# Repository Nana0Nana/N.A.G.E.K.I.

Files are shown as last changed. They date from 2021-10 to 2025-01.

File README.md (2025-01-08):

# N.A.G.E.K.I.
# [PLEASE CHECK Main Project](https://github.com/Nana0Nana/NAGEKI)
# ↑ This page dont have update,please check the main ↑
# 这个页面停止更新，请查看主项目↑↑

## A cheap，simple，Ongeki controller Use Keyboard Simulation and Mouse Simulation to controller the ongeki game. Using Pro-micro control.
## [中文版介绍 Chinese version](https://github.com/Nana0Nana/N.A.G.E.K.I./blob/main/README_CN.md)

# Befor download

## FOR All the blueprint,I __didnt__ do the Screw holes, so thats mean you need use drill to creat a hold for screw,I use M3x25 screw to fix all the part.

# First
## you need print the PCB and you need a Promicro to control.

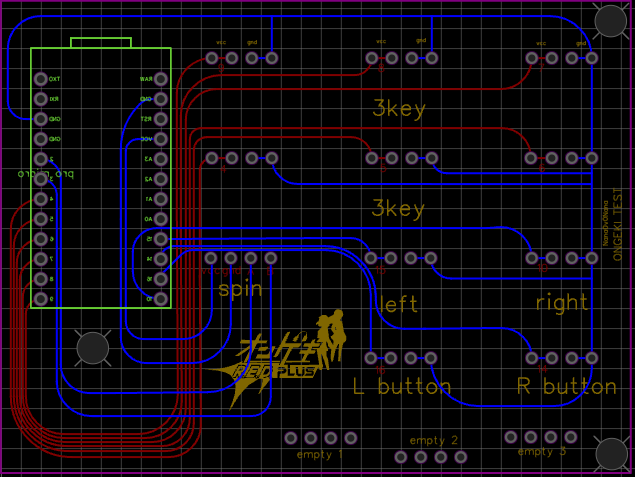
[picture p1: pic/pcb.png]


## I already ping the ports out so you just need connect them.

# For main.

I recommend you use the 15 or 20mm Density wood board

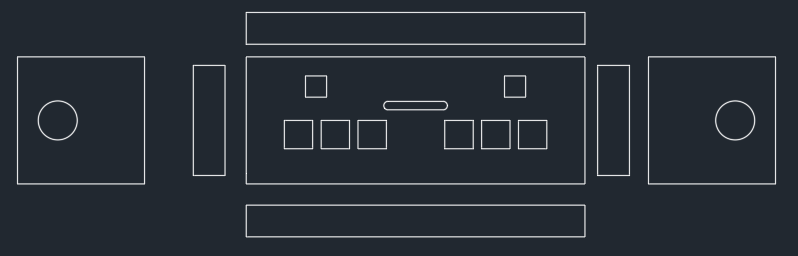
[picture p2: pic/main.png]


## details

For the main button,I get 67x67mm hole,thats a really big size than the button you got.But you will get the Acrylic board,that will fix the hole.
you need 60x60mm button.

for menu button,I get 50x50mm hole,same,that hold will a bit large than the button size,so you need the Acrylic board.
you nedd 44x44mm button

for side button,I use the 100x100mm button,thats the cheap and easy way to solve the side button problem.
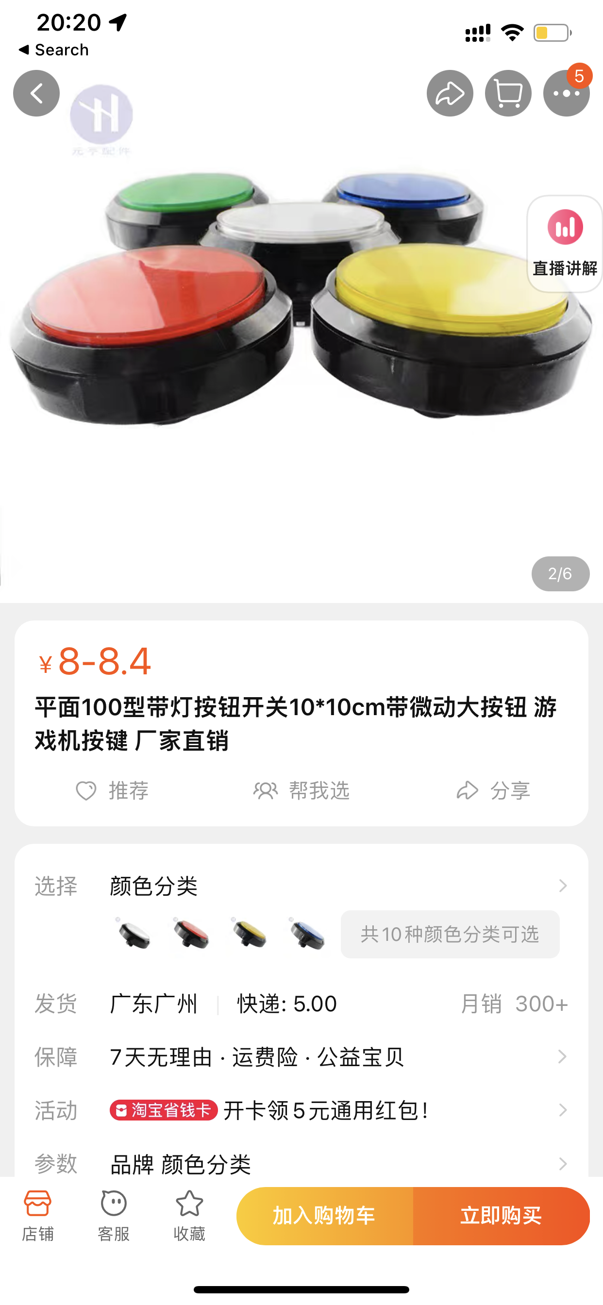
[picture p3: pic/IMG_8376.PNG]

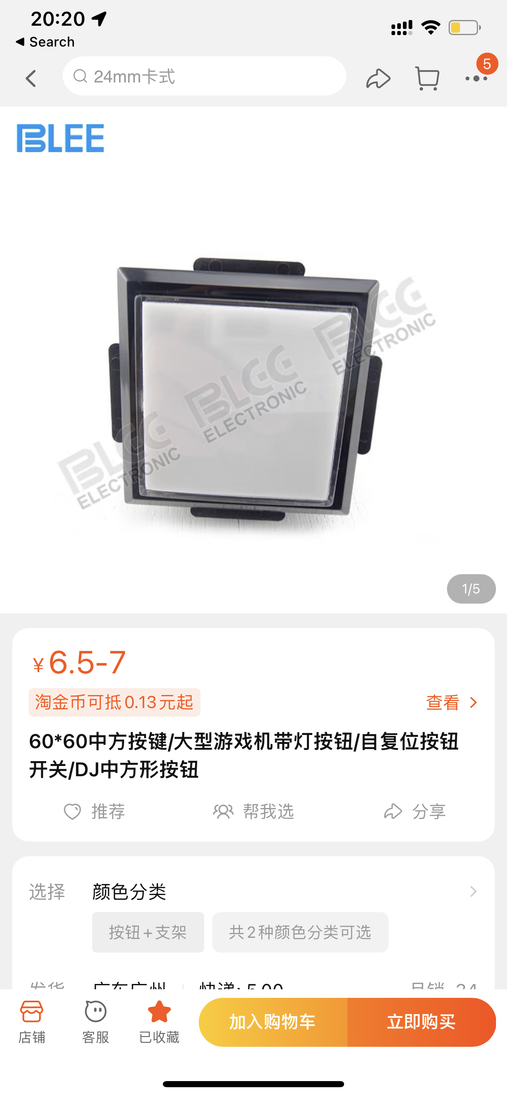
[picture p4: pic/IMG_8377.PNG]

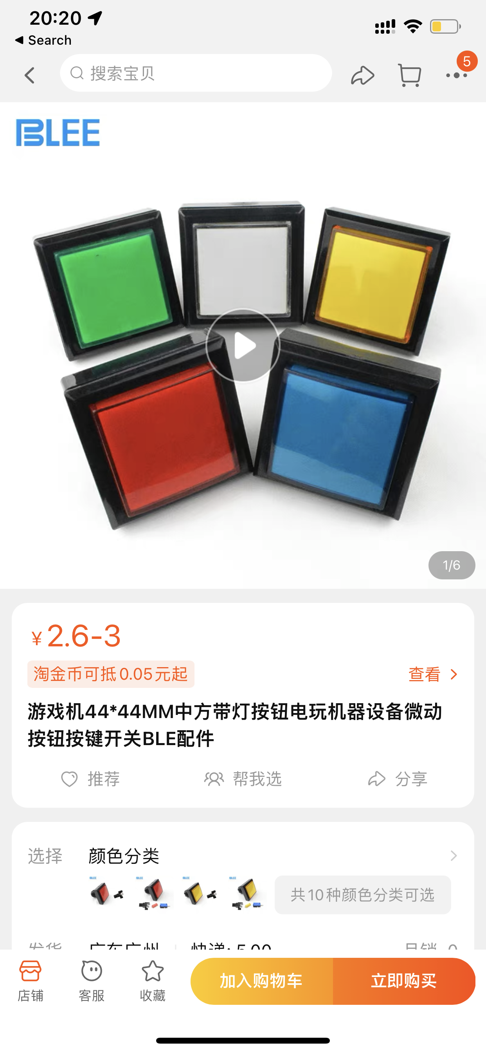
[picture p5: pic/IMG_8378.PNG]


## Then,you need a encoder to control the lever.
### also you need a frame to fixed encoder.
## For the lever,you can buy the wood stick or the iron stick,then you can try to use some gear or something to fixed the stick and encoder,I will post here if i get the good way to fixed them.

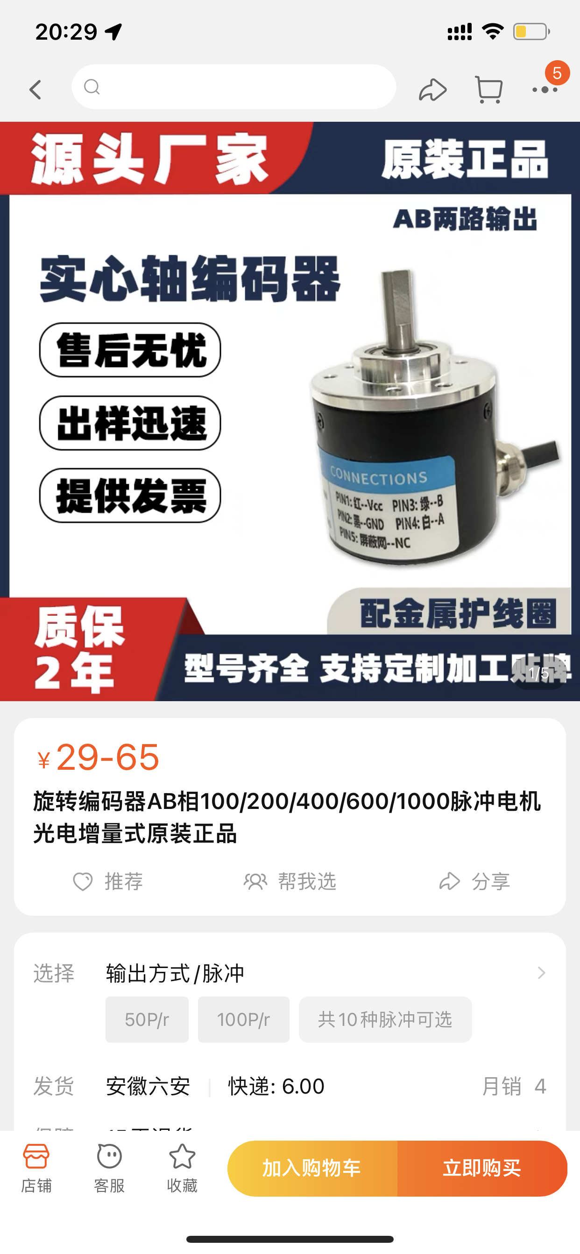
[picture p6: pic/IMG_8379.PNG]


# For surface.
I recommend you use the UV print on the surface,I used 2mm thickness board.

Also,you can just use the Acrylic board on surface.

## !!! Important !!!

you must have the surface board,because the main board size will a bit larger than the button you got! you need surface board to fix that!!!

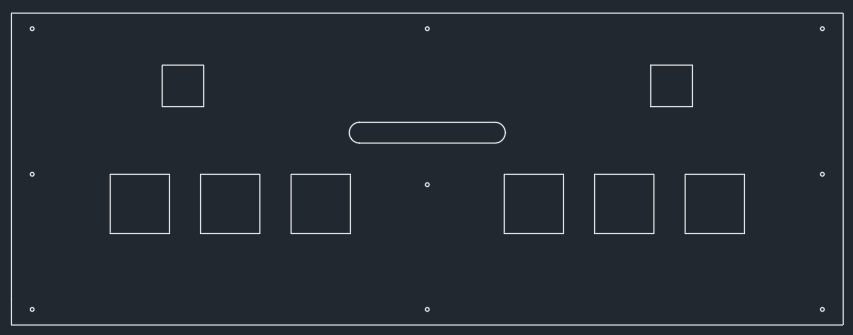
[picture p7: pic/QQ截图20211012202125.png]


and you can use UV print with this pic.

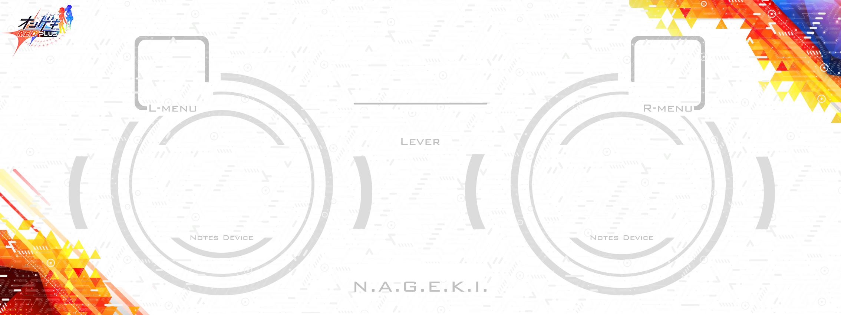
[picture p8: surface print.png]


# Afer everything,you will get a complete NAGEKI controller.

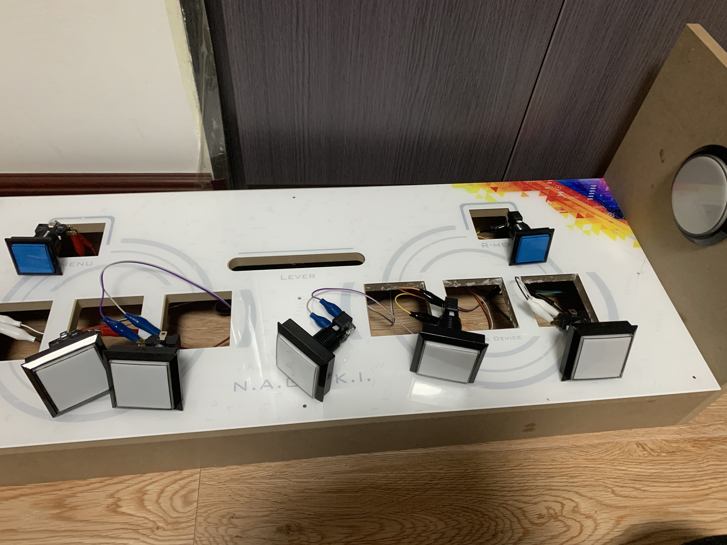
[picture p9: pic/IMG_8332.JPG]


# When you ready for the frame,just use the arudio write the code(i already post it)

# ENJOY YOUR ONGEKI GAME :)

# ！！！attention！！！
# Im not the professional person for design and codeing,all the idea or design just form my hobby,and I never learn the pcb writing or the CAD drawing.SO the project 100% will have alot of problem,So if you find some problem or you can help me build the project better,pls email me at 2391626794@qq.com  or  Nya@nananana.net.

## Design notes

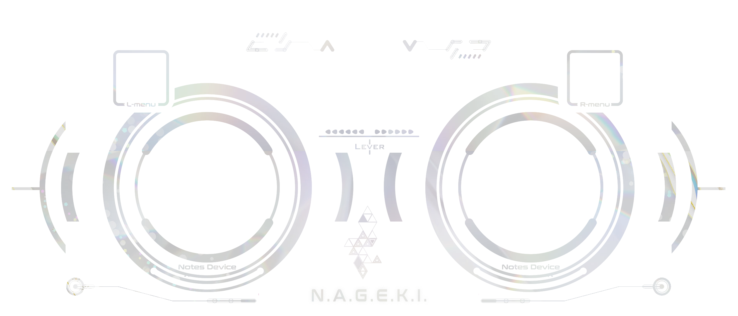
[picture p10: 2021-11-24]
skin/NAGEKI 2.1 UV BRIGHT.png

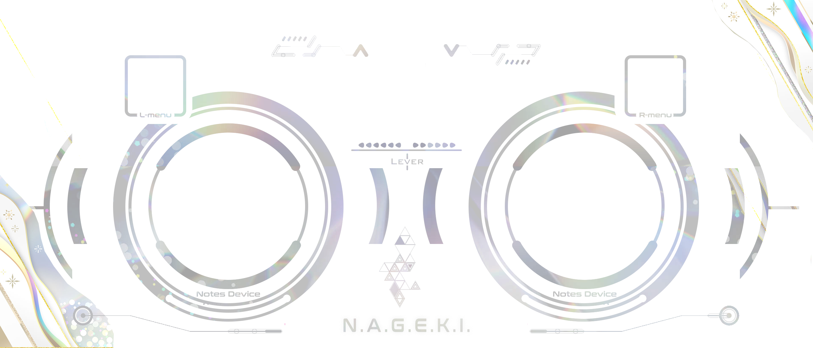
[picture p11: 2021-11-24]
skin/NAGEKI 2.1 UV BRIGHT 2.png

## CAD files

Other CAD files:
ongeki main.dwg
ongeki surface.dwg

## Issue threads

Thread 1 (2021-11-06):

关于编码器

senzi96, 2021-11-06:
想请问下大佬用什么输出方式和脉冲的编码器比较好呢

Nana0Nana, 2021-11-06:
集电极开路，100-400p以内

senzi96, 2021-11-06:
> 集电极开路，100-400p以内

还有想请问一下，刚刚用100p的编码器更新到2.0固件出现了游戏和系统中位置抖动的问题，1.0固件的时候没有这个问题，请问是编码器脉冲较低么还可能是什么情况导致的。

Nana0Nana, 2021-11-06:
> > 集电极开路，100-400p以内
>
> 还有想请问一下，刚刚用100p的编码器更新到2.0固件出现了游戏和系统中位置抖动的问题，1.0固件的时候没有这个问题，请问是编码器脉冲较低么还可能是什么情况导致的。

如果用的是电位器，请把编码器部分代码删除，如果是编码器请把电位器部分代码删除，并且编码器屏蔽线与GND相连

Nana0Nana, 2021-11-06:
> > 集电极开路，100-400p以内
>
> 还有想请问一下，刚刚用100p的编码器更新到2.0固件出现了游戏和系统中位置抖动的问题，1.0固件的时候没有这个问题，请问是编码器脉冲较低么还可能是什么情况导致的。

如果是旋转编码器就删除lever部分代码，或者直接从loop中删除lever函数，如果是电位器就删除encoder

senzi96, 2021-11-07:
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

谢谢您！问题解决了。还有就是请问您觉得旋转编码器和电位器比哪个玩起来更好延迟更低呢？

Nana0Nana, 2021-11-07:
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

延迟理论上来说电位器会更低，但体验不出来，电位器数值更加精准，编码器方便固定

senzi96, 2021-11-09:
谢谢您！完美地解决了我的问题！

Closed 2021-11-09.

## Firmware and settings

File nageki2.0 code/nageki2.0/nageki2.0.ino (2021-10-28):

#include "Mouse.h"
#include "./src/Encoder/Encoder.h"
//thanks my hero :)
//https://github.com/Reyn-Mukai/SDVX-DIY/tree/Standard
//from SDVX-DIY CODE
#include "Keyboard.h"
#include "Mouse.h"
#include <Adafruit_NeoPixel.h>

/*WS2812*/

/*Pot*/
int Sensor=A0;//将A0引脚取名为Sensor/ A0 pin Named Sensor
int SensorRead=0;
int newdata=0;
int inputValue=0;
int a;

/* button pin */
const int buttonPin1 = 9;          // Key left 1
const int buttonPin2 = 8;          // Key left 2
const int buttonPin3 = 7;          // Key left 3

const int buttonPin4 = 6;          // Key Right 4
const int buttonPin5 = 5;          // Key Right 5
const int buttonPin6 = 4;          // Key Right 6


const int FunctionL = 15;          // FKey left 
const int FunctionR = 10;          // FKey right

const int SideL = 16;          // SKey left 
const int SideR = 14;          // SKey right

/* Encoder pin */
/* 如果发现转动方向是反的就把3和2的位置调换一下*/
/*Switch "3" and "2" if the spin way was wrong*/
#define ENC_1_PIN_A 2
#define ENC_1_PIN_B 3


/* Encoder */
Encoder encLeft(ENC_1_PIN_A, ENC_1_PIN_B);


void setup() {
  Serial.begin(9600);
  // 初始化按键引脚，如果没有上拉电阻，需要使用INPUT_PULLUP/Pin Mode.
  pinMode(buttonPin1, INPUT_PULLUP);
  pinMode(buttonPin2, INPUT_PULLUP);
  pinMode(buttonPin3, INPUT_PULLUP);
  pinMode(buttonPin4, INPUT_PULLUP);
  pinMode(buttonPin5, INPUT_PULLUP);
  pinMode(buttonPin6, INPUT_PULLUP);
  pinMode(FunctionL, INPUT_PULLUP);
  pinMode(FunctionR, INPUT_PULLUP);
  pinMode(SideL, INPUT_PULLUP);
  pinMode(SideR, INPUT_PULLUP);
  // 初始化模拟键盘功能/Begin keyboard
  Keyboard.begin();
  Keyboard.releaseAll(); //所有键盘按键松开/Releasekeyboard
  //初始化鼠标/Begin Mousemove
  Mouse.begin();
  //归零编码器/encoder write 0
  encLeft.write(0);
  }

void Keys(){
   if (digitalRead(buttonPin1) == LOW){ //按键1/Key1
    Keyboard.press('J');
   }
   else {
    Keyboard.release('J');
}

   if (digitalRead(buttonPin2) == LOW){ //按键2/Key2
    Keyboard.press('K');
   }
   else {
    Keyboard.release('K');
}

   if (digitalRead(buttonPin3) == LOW){ //按键3/Key3
    Keyboard.press('L');
   }
   else {
    Keyboard.release('L');
}
if (digitalRead(buttonPin4) == LOW){ //按键4/Key 4
    Keyboard.press('A');
   }
   else {
    Keyboard.release('A');
}

   if (digitalRead(buttonPin5) == LOW){ //按键5/Key 5
    Keyboard.press('S');
   }
   else {
    Keyboard.release('S');
}

   if (digitalRead(buttonPin6) == LOW){ //按键6/Key 6
    Keyboard.press('D');
   }
   else {
    Keyboard.release('D');
}
}
void Function(){
  if (digitalRead(FunctionL) == LOW){ //功能键左/Menu L
    Keyboard.press('R');
   }
   else {
    Keyboard.release('R');
}
  if (digitalRead(FunctionR) == LOW){ //功能键右/Menu R
    Keyboard.press('U');
   }
   else {
    Keyboard.release('U');
}
}
void Side(){
    if (digitalRead(SideL) == LOW){ //侧键1/Side 1
    Keyboard.press('P');
   }
   else {
    Keyboard.release('P');
}
  if (digitalRead(SideR) == LOW){ //侧键2/Side 2
    Keyboard.press('Q');
   }
   else {
    Keyboard.release('Q');
}
}
void encFuncLeft(){
  updateMousePositionLeft();
}

void updateMousePositionLeft()
{
  static int prev_value = 0;
  int a;
  a = encLeft.read();
  Mouse.move((prev_value - a) * 2, 0, 0);
  prev_value = a;
}


void lever() 
{
    SensorRead=analogRead(Sensor);//读出Sensor的值并将它赋给SensorRead/Read Sensor and wirte for SensorRead
    newdata=map(SensorRead,0,1023,0,255);
    if (newdata >= 255)
    {
      newdata=(newdata - 128);
      Serial.println(newdata);
      }
    else if (newdata <= 255)
     {
      newdata=(newdata - 127);
      Serial.println(newdata);
      }
    }

void move()

{
  static int prev_value = 0;
  a = newdata;
  Mouse.move((prev_value - a) * 2, 0, 0);
  prev_value = a;
  
}

void loop()
  {
  Keys();
  Function();
  Side();
  encFuncLeft();
  updateMousePositionLeft();
  lever();
  move();
  }

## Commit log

2021-10-12 N.A.G.E.K.I. V1.0
    thats the first version for NAGEKI
    Still have lot problem
    Ver.2.0 developing.....
    [ongeki main.dwg, ongeki side buttonv1 v2（testing）.obj, ongeki surface.dwg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]
2021-10-12 NEW PCB,fix some problem
    fix some problem
    [ongeki2.0_2021-10-12.pcbdoc]
2021-10-18 Encoder code form https://github.com/Reyn-Mukai/SDVX-DIY/tree/Standard
    https://github.com/Reyn-Mukai/SDVX-DIY/tree/Standard
2021-10-27 DO NOT USE
    [ongeki2.0_2021-08-10.pcbdoc]
2021-10-27 PCB FILE
2021-10-28 v1 pcb
    OLD
2021-10-28 PCB V1
    OLD PCB
2021-10-28 V2 PCB
    NEW PCB
2021-10-28 SIDE PCB
